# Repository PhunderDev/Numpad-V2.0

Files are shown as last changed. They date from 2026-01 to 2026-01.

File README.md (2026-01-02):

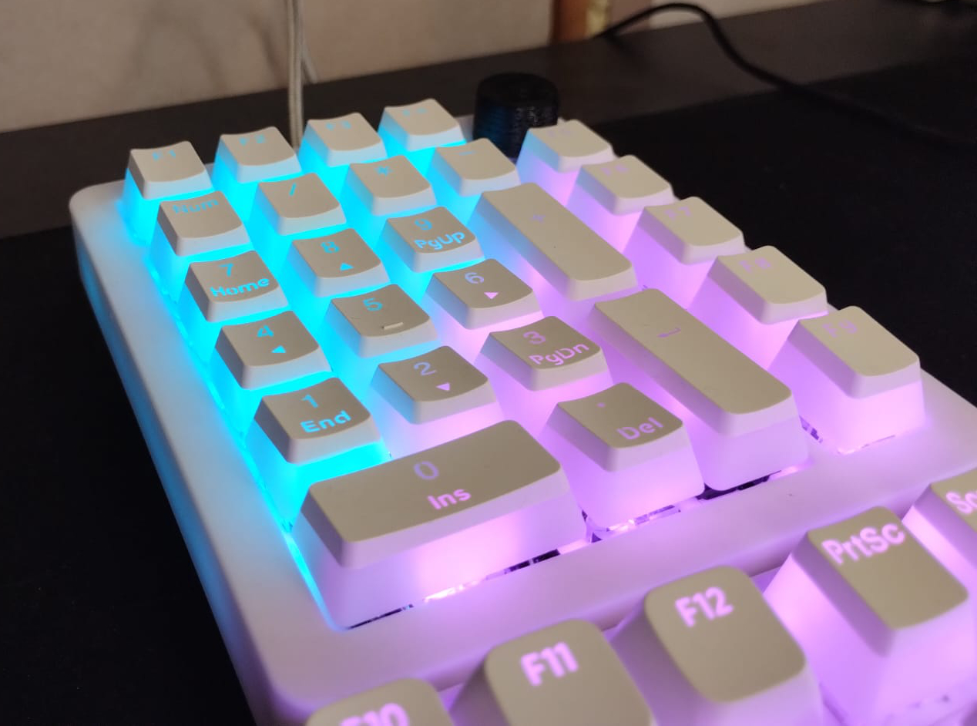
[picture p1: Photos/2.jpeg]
Numpad Photo


# About the project
This project is my answer to the lack of a satifying full-sized keyboard on the market (in a reasonable price). It is a numpad with 9 extra keys and a volume knob.
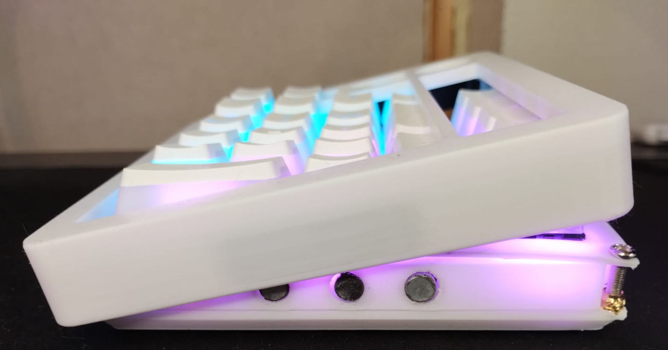
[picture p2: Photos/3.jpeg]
Numpad Magnets Photo
The numpad uses 6 magnets and magnetic tape embeded into the top case, which allow the user to switch the top case quickly, making customization easier. 

The firmware is written in C++ for raspberry pi pico (1), however it can surely be built for other microcontrollers.

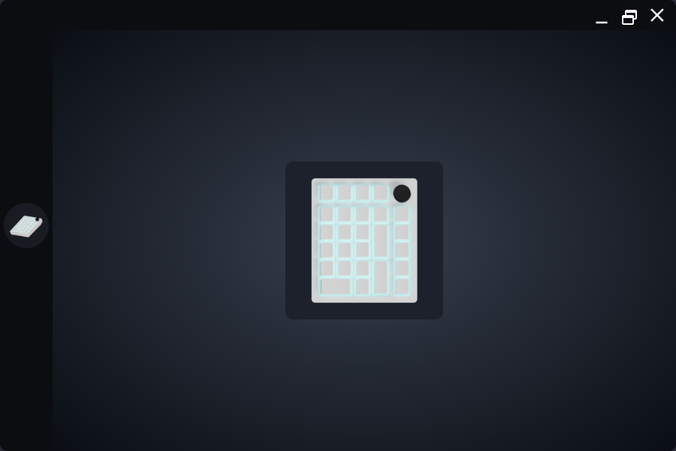
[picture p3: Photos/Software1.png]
Software Screenshot 1
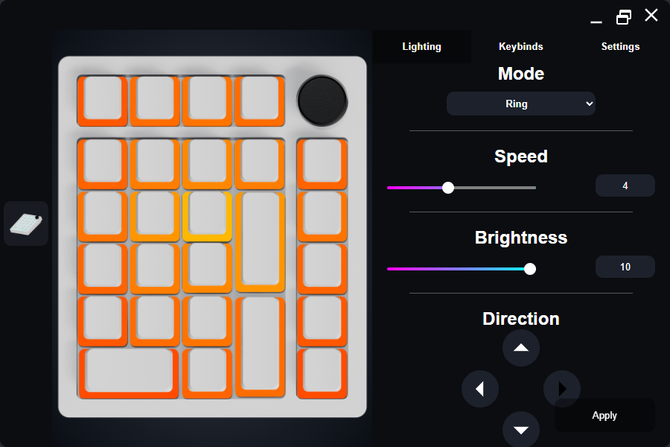
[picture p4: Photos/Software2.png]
Software Screenshot 2
The software part uses angular and electron (unfortunatelly your ram will likely suffer due to that, but the software doesn't need to be on all the time). The software allows the user to change the "global settings" of the lighting, and the "local settings" for each of the keys, not restricting to only the provided modes.   
No build setup is provided yet, but electron packager is included in the libraries already. You might have to tweak the build settings a bit.

Otherwise you can try the software by running the command
```bash
npm run electronTest
```

# Main Goal
The software is supposed to serve as a hub for custom RGB devices and includes a modular way of adding effects so adding any custom modes should be relatively easy.

# Project's Structure
The files are segregated depending on whether they are related to firmware, software, or physical build. The folder "Physical/Print Models" contains the STL files required to build the Numpad.

# Components
The following components were to assemble the numpad:
- Raspberry pi pico (1)
- Adafruit 4090 USB-C Breakout Board
- Addressable WS2812B LED strip
- EC12 20mm Rotary Encoder
- Magnetic Tape
- Magnets (6mm diameter | 3mm depth)
- 26 Switches (Any will work)
- Some jumper wires

# Assembly Instructions
Coming Soon

# Future of the project
The project is open for contributions and is supposed to be community-driven, therefore if there is any feature you would like to see-code it and share with the others.

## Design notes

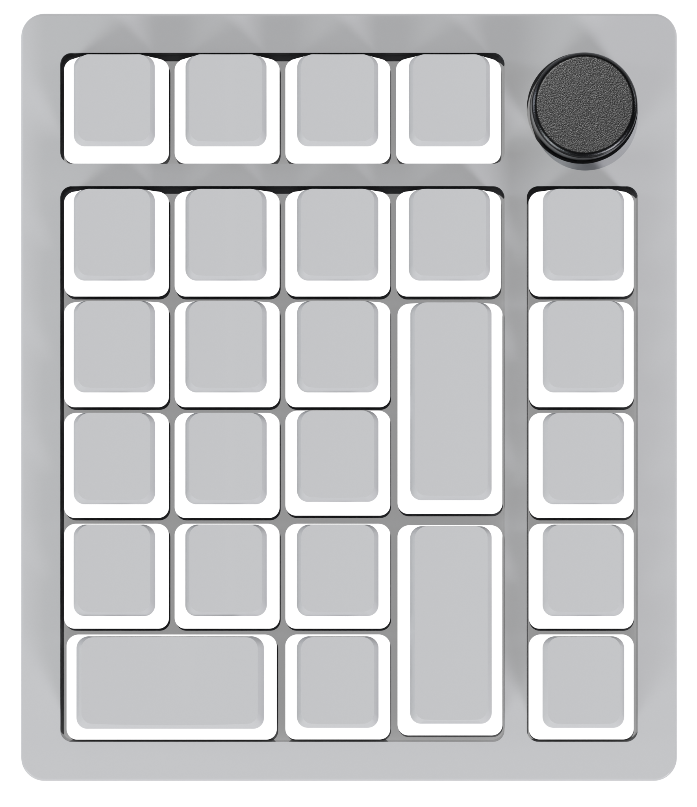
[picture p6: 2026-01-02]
Physical/Renders/Render1.png

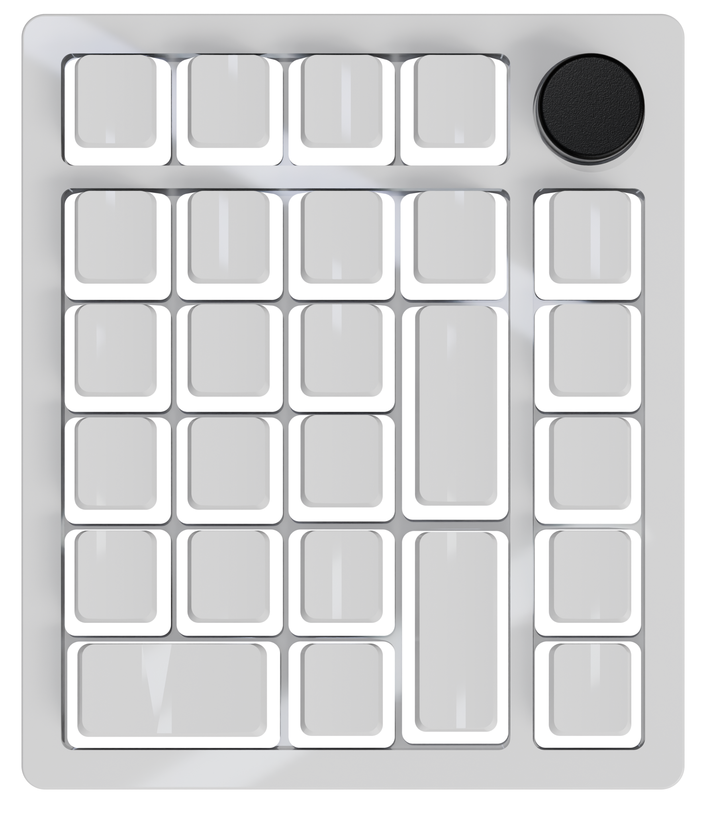
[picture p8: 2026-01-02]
Physical/Renders/Render4.png

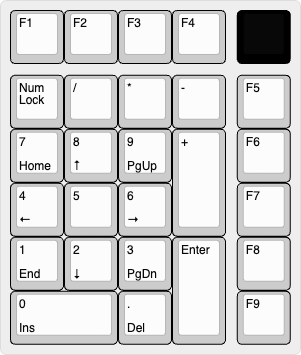
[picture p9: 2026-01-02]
Physical/Plate/keyboard-layout.png

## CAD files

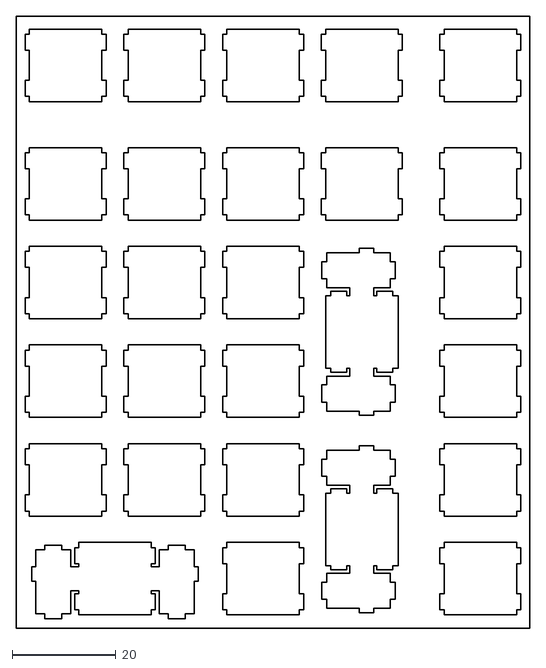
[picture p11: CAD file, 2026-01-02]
Physical/Plate/keyboard-layout.dxf
99.1 x 118.1

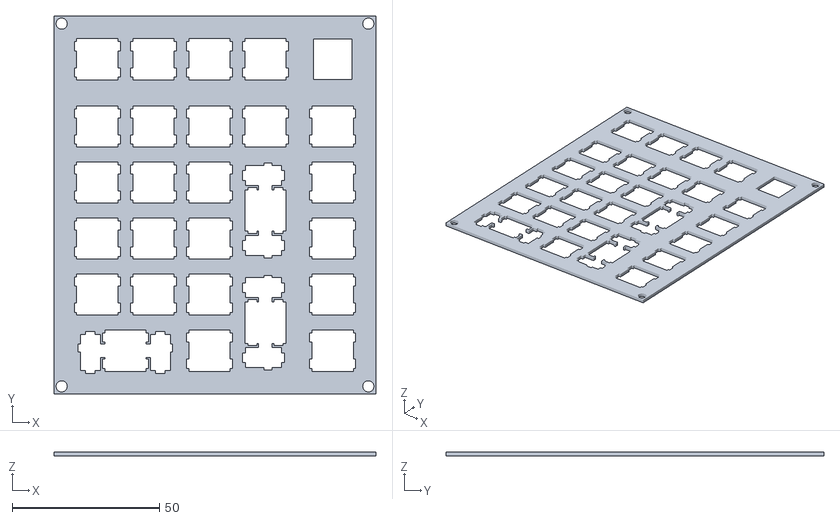
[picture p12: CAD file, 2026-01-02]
Physical/Print Models/Plate.stl
109.5 x 128.5 x 1.50

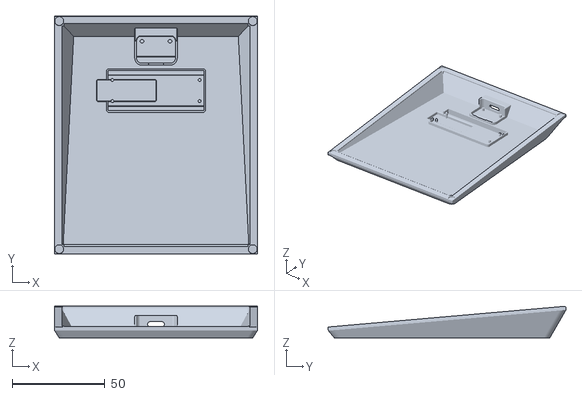
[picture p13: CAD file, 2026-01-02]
Physical/Print Models/Bottom Case.stl
109.5 x 128.2 x 17.0

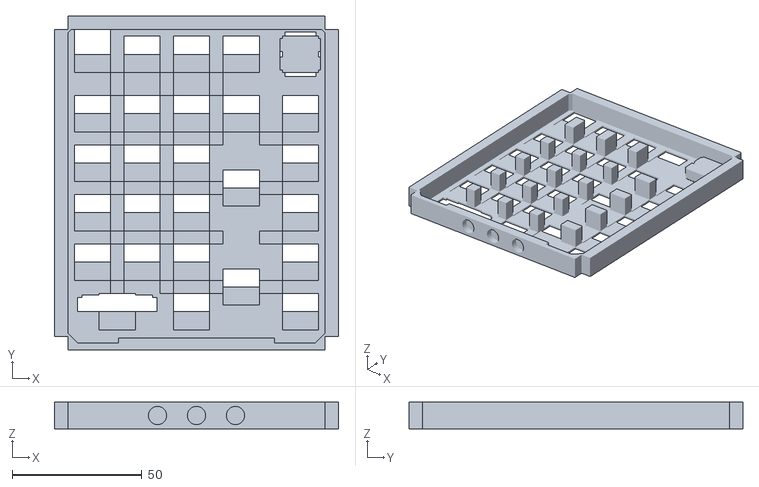
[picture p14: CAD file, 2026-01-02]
Physical/Print Models/Cables Separator.stl
109.5 x 128.5 x 10.2

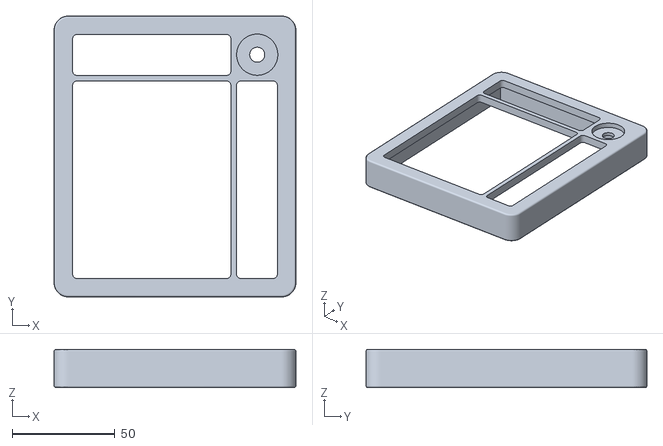
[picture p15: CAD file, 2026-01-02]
Physical/Print Models/Top Case.stl
117.7 x 136.7 x 18.7

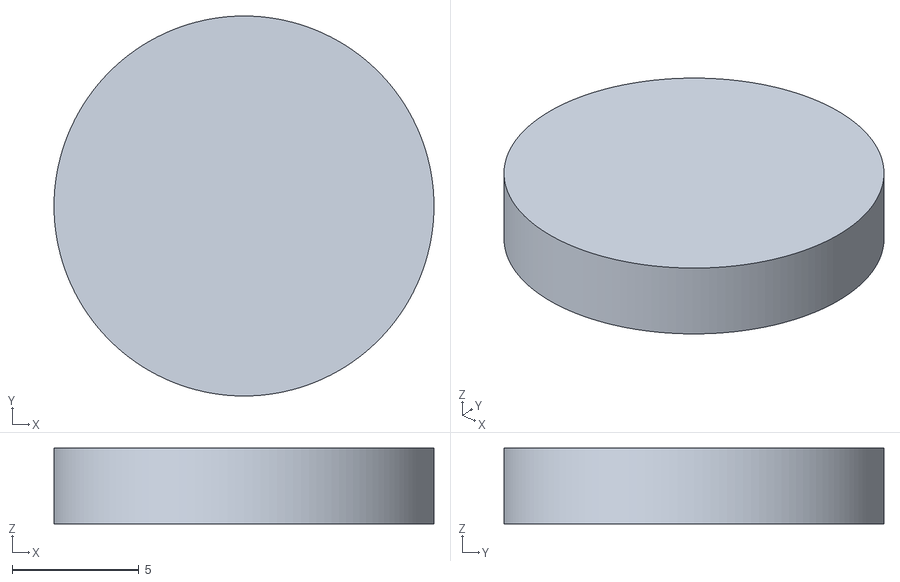
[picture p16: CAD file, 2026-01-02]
Physical/Print Models/Rubber Leg.stl
15.0 x 15.0 x 3.00

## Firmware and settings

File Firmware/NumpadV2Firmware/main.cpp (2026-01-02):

#include <stdlib.h>
#include <stdio.h>
#include <string.h>
#include <pico/stdio.h>
#include <pico/bootrom.h>
#include <hardware/gpio.h>

#include "bsp/board_api.h"
#include "tusb.h"
#include "usb_descriptors.h"

#include "WS2812.hpp"

#include "hardware/flash.h"
#include <tuple>
#include <algorithm>
#include <cmath>

// Start Address For Save Files In Flash
#define USER_DATA_FLASH_TARGET_OFFSET (PICO_FLASH_SIZE_BYTES - FLASH_SECTOR_SIZE)


#define LED_PIN 22
#define LED_LENGTH 26
#define ENCODER_SW 18
#define ENCODER_A 20
#define ENCODER_B 21
#define LEDMatrixWidth 5
#define LEDMatrixHeight 6
#define ConstantLEDSpeedMultiplier 20
#define ReverseKnob true
const int LEDDataLength = (LED_LENGTH * 7) + std::ceil((LED_LENGTH * 7) / (double)CFG_TUD_HID_EP_BUFSIZE);


//////////////////////////////////////////////////////
/// Wiring Config
//////////////////////////////////////////////////////
const int Columns[LEDMatrixWidth] = {6, 5, 4, 3, 2};
const int Rows[LEDMatrixHeight] = {7, 8, 9, 10, 11, 12};
const int DebounceTime = 10;
const int Knob_RotateDebounceTime = 10;
const int ConsumerDebounceTime = 300;
const int ConsumerEmptyDebounceTime = 50;
bool ConsumerEmptySent = false;
const int LEDRefreshTime = 20;
bool IsAsleep = false;

const int LEDMatrixIndexConfiguration[LEDMatrixHeight][LEDMatrixWidth] = {
  {0, 10, 11, 20, -1},
  {1, 9, 12, 19, 21},
  {2, 8, 13, 18, 22},
  {3, 7, 14, -1, 23},
  {4, 6, 15, 17, 24},
  {5, -1, 16, -1, 25}
}; 

bool CurrentReportMatrix[LEDMatrixHeight][LEDMatrixWidth] = {
  {false, false, false, false, false},
  {false, false, false, false, false},
  {false, false, false, false, false},
  {false, false, false, false, false},
  {false, false, false, false, false},
  {false, false, false, false, false}
};

int PreviousReportMatrix[LEDMatrixHeight][LEDMatrixWidth] = {
  {-1, -1, -1, -1, -1},
  {-1, -1, -1, -1, -1},
  {-1, -1, -1, -1, -1},
  {-1, -1, -1, -1, -1},
  {-1, -1, -1, -1, -1},
  {-1, -1, -1, -1, -1}
};

//////////////////////////////////////////////////////
/// Firmware Variables
//////////////////////////////////////////////////////
uint32_t DeltaTime = 0;
uint32_t LastTimeUpdated = 0;


//////////////////////////////////////////////////////
/// Keyboard Loop Variables
//////////////////////////////////////////////////////
uint32_t SwitchMatrix_DeltaTime = 0;
int CurrentColIndex = 0;
bool WaitingForDebounce = false;


uint32_t ReportSend_DeltaTime = 0;
uint32_t Knob_DeltaTime = 0;
uint32_t Knob_DebounceTime = Knob_RotateDebounceTime;
bool LastStateA = false;
bool ShouldDebounceKnob = false;




//////////////////////////////////////////////////////
/// LED Variables
//////////////////////////////////////////////////////
class LEDSettings {
  public:
  uint8_t StartColor_R;
  uint8_t StartColor_G;
  uint8_t StartColor_B;
  uint8_t Brightness;
  uint8_t Mode;
  uint8_t Speed;
  uint8_t Direction;

  uint8_t CurrentColor_R;
  uint8_t CurrentColor_G;
  uint8_t CurrentColor_B;
};
WS2812* ledStrip = nullptr;
int LastLEDSet = 0;
int LastLEDSettingsModified = 0;
uint32_t LED_DeltaTime = 0;
uint8_t LEDDataToSave[LEDDataLength];
int LastLEDDataToSaveIndex = 0;
LEDSettings LEDSettingsArray[LED_LENGTH];





//////////////////////////////////////////////////////
/// Device Settings
//////////////////////////////////////////////////////

uint8_t SwitchMatrixKeyBindConfiguration[LEDMatrixHeight][LEDMatrixWidth] = {
  {0x68, 0x69, 0x6A, 0x6B, 0x00},   // F13, F14, F15, F16, null
  {0x53, 0x54, 0x55, 0x56, 0x6C},   // NumLock, /, *, -, F17
  {0x5F, 0x60, 0x61, 0x57, 0x6D},   // 7, 8, 9, +, F18
  {0x5C, 0x5D, 0x5E, 0x00, 0x6E},   // 4, 5, 6, null, F19
  {0x59, 0x5A, 0x5B, 0x58, 0x6F},   // 1, 2, 3, ENTER, F20
  {0x62, 0x00, 0x63, 0x00, 0x70}    // 0, null, ., null, F21
};

uint32_t KeyboardPollingTime = 8;




//////////////////////////////////////////////////////
/// Flash Save & Load LEDs
//////////////////////////////////////////////////////

bool ProcessLEDSettings(uint8_t const* buffer, uint16_t bufsize) {
  
  LEDDataToSave[LastLEDDataToSaveIndex] = buffer[0];
  LastLEDDataToSaveIndex++;
  for(int i = 1; i < bufsize; i+=7) {

    int YInArray = LastLEDSet/LEDMatrixWidth;
    int XInArray = LastLEDSet%LEDMatrixWidth;
    while(LEDMatrixIndexConfiguration[YInArray][XInArray] == -1 && !(YInArray == LEDMatrixHeight -1 && XInArray == LEDMatrixWidth - 1)) {
      LastLEDSet++;
      YInArray = LastLEDSet/LEDMatrixWidth;
      XInArray = LastLEDSet%LEDMatrixWidth;
    }

    LEDSettings NewLEDSettings;
    NewLEDSettings.StartColor_R = buffer[i];
    NewLEDSettings.StartColor_G = buffer[i+1];
    NewLEDSettings.StartColor_B = buffer[i+2];
    NewLEDSettings.Mode = buffer[i+3];
    NewLEDSettings.Speed = buffer[i+4];
    NewLEDSettings.Brightness = (buffer[i+5]);
    NewLEDSettings.Direction = buffer[i+6];


    for(int e = 0; e < 7; e++) LEDDataToSave[LastLEDDataToSaveIndex+e] = buffer[i+e];
    LastLEDDataToSaveIndex+=7;


    NewLEDSettings.CurrentColor_R = NewLEDSettings.StartColor_R;
    NewLEDSettings.CurrentColor_G = NewLEDSettings.StartColor_G;
    NewLEDSettings.CurrentColor_B = NewLEDSettings.StartColor_B;

    LEDSettingsArray[LastLEDSettingsModified] = NewLEDSettings;

    float Brightness = NewLEDSettings.Brightness/10.0;

    (*ledStrip).setPixelColor(LEDMatrixIndexConfiguration[YInArray][XInArray], WS2812::RGB(NewLEDSettings.CurrentColor_R * Brightness, NewLEDSettings.CurrentColor_G * Brightness, NewLEDSettings.CurrentColor_B * Brightness));
    LastLEDSet++;
    LastLEDSettingsModified++;
    if(LEDMatrixIndexConfiguration[YInArray][XInArray] == LED_LENGTH - 1) {
      (*ledStrip).show();
      LastLEDSet = 0;
      LastLEDSettingsModified = 0;
      LastLEDDataToSaveIndex = 0;
      return true;
      break;
    }
  }
  return false;
}

void SaveLEDSettings(const uint8_t* data) {
    if (data == nullptr || LEDDataLength > FLASH_PAGE_SIZE) {
        return;
    }

    uint8_t buffer[FLASH_PAGE_SIZE];
    memset(buffer, 0xFF, sizeof(buffer)); // Erase the Buffer
    memcpy(buffer, data, LEDDataLength); // Set the Buffer

    flash_range_erase(USER_DATA_FLASH_TARGET_OFFSET, FLASH_SECTOR_SIZE);
    flash_range_program(USER_DATA_FLASH_TARGET_OFFSET, buffer, FLASH_PAGE_SIZE);
}

void LoadLEDSettings(void) {
    memcpy(LEDDataToSave, reinterpret_cast<const uint8_t*>(XIP_BASE + USER_DATA_FLASH_TARGET_OFFSET), LEDDataLength);
}



//////////////////////////////////////////////////////
/// USB HID
//////////////////////////////////////////////////////

void tud_hid_set_report_cb(uint8_t itf, uint8_t report_id, hid_report_type_t report_type, uint8_t const* buffer, uint16_t bufsize) {

    // buffer[0] => Type of update
    if (itf == ITF_NUM_HID2 && buffer[0] == 1 && bufsize == CFG_TUD_HID_EP_BUFSIZE){
      bool Finished = ProcessLEDSettings(buffer, bufsize);
      if(Finished) {
        SaveLEDSettings(LEDDataToSave);
      }

    }
}

uint16_t tud_hid_get_report_cb(uint8_t itf, uint8_t report_id, hid_report_type_t report_type, uint8_t* buffer, uint16_t reqlen) {
    return 0;
}


// PC Sleep
void tud_suspend_cb(bool remote_wakeup_en) {
  IsAsleep = true;
  (*ledStrip).fill(WS2812::RGB(0, 0, 0));
  (*ledStrip).show();
}
int InitLEDSettings();
// PC Wakey Wakey
void tud_resume_cb(void) {
  IsAsleep = false;
  InitLEDSettings();
}



//////////////////////////////////////////////////////
/// Keyboard Functionalities
//////////////////////////////////////////////////////
void send_keyboard_report(uint8_t modifier, uint8_t keycodes[6])
{
  if (!tud_ready()) return;

  // [modifier, reserved, keycode1, keycode2, ...]
  uint8_t report[8] = {0}; 
  report[0] = modifier;
  report[1] = 0x00;
  report[2] = keycodes[0];
  report[3] = keycodes[1];
  report[4] = keycodes[2];
  report[5] = keycodes[3];
  report[6] = keycodes[4];
  report[7] = keycodes[5];

  tud_hid_n_report(ITF_NUM_HID1, REPORT_ID_KEYBOARD, report, sizeof(report));
}

void send_consumer_report(uint16_t consumer_code)
{
  if (!tud_ready()) return;
  
  tud_hid_n_report(ITF_NUM_HID1, REPORT_ID_CONSUMER_CONTROL, &consumer_code, 2);
}

void SwitchMatrixLoop() {
  //Wait For The Right Time To Update

  if(!WaitingForDebounce) {
  
    gpio_put(Columns[CurrentColIndex], 1);
    WaitingForDebounce = true;
    return;
  }

  

  if(SwitchMatrix_DeltaTime >= DebounceTime) {
    // Register The Rows
    for(int row = 0; row < sizeof(Rows) / sizeof(Rows[0]); row++) {

      if(gpio_get(Rows[row]) != 0 && SwitchMatrixKeyBindConfiguration[row][CurrentColIndex] == 0x69) {
        if(ShouldDebounceKnob && Knob_DeltaTime < Knob_DebounceTime) continue;
        send_consumer_report(HID_USAGE_CONSUMER_SCAN_PREVIOUS);
        Knob_DebounceTime = ConsumerDebounceTime;
        ShouldDebounceKnob = true;
        ConsumerEmptySent = false;
        continue;
      }
      if(gpio_get(Rows[row]) != 0 && SwitchMatrixKeyBindConfiguration[row][CurrentColIndex] == 0x6A) {
        if(ShouldDebounceKnob && Knob_DeltaTime < Knob_DebounceTime) continue;
        send_consumer_report(HID_USAGE_CONSUMER_PLAY_PAUSE);
        Knob_DebounceTime = ConsumerDebounceTime;
        ShouldDebounceKnob = true;
        ConsumerEmptySent = false;
        continue;
      }
      if(gpio_get(Rows[row]) != 0 && SwitchMatrixKeyBindConfiguration[row][CurrentColIndex] == 0x6B) {
        if(ShouldDebounceKnob && Knob_DeltaTime < Knob_DebounceTime) continue;
        send_consumer_report(HID_USAGE_CONSUMER_SCAN_NEXT);
        Knob_DebounceTime = ConsumerDebounceTime;
        ShouldDebounceKnob = true;
        ConsumerEmptySent = false;
        continue;
      }

      CurrentReportMatrix[row][CurrentColIndex] = gpio_get(Rows[row]) != 0;
    }
    gpio_put(Columns[CurrentColIndex], 0);
    
    // Shift To The Next Column and/or Row if necessary
    CurrentColIndex += 1;
    if(CurrentColIndex == sizeof(Columns)/sizeof(Columns[0])) {CurrentColIndex = 0;}

    // Reset Timer
    SwitchMatrix_DeltaTime = 0;
    WaitingForDebounce = false;
  }



}

void KeyboardReportLoop() {
  if(ReportSend_DeltaTime < KeyboardPollingTime) return;
  
  uint8_t report[6] = {0, 0, 0, 0, 0, 0};

  int amount = 0;
  for(int col = 0; col < sizeof(Columns) / sizeof(Columns[0]); col++) {
    for(int row = 0; row < sizeof(Rows) / sizeof(Rows[0]); row++) {

      if(amount >= 6) break;

      if(!CurrentReportMatrix[row][col] && PreviousReportMatrix[row][col] != -1) {
        report[PreviousReportMatrix[row][col]] = 0x00;
        // Set as Sent/Released
        PreviousReportMatrix[row][col] = -1;
        amount += 1;
      }
      else if(CurrentReportMatrix[row][col] && PreviousReportMatrix[row][col] == -1) {
        report[amount] = SwitchMatrixKeyBindConfiguration[row][col];
        // Set as Pressed
        PreviousReportMatrix[row][col] = amount;
        amount += 1;
      }
    }

    if(amount == 6) break;
  }

  if(amount != 0) {
    if(IsAsleep) {
      tud_remote_wakeup();
      return;
    }
    send_keyboard_report(0, report);
  }
}


void KnobReportLoop() {
  if(ShouldDebounceKnob && Knob_DeltaTime < Knob_DebounceTime) {
    if(Knob_DeltaTime >= ConsumerEmptyDebounceTime && !ConsumerEmptySent) {
      ConsumerEmptySent = true;
      send_consumer_report(0);
    }
    return;
  }
  ShouldDebounceKnob = false;
  Knob_DeltaTime = 0;

  if(gpio_get(ENCODER_SW) == 0) {
    send_consumer_report(HID_USAGE_CONSUMER_MUTE);
    Knob_DebounceTime = ConsumerDebounceTime;
    ShouldDebounceKnob = true;
    ConsumerEmptySent = false;
    return;
  }

  Knob_DebounceTime = Knob_RotateDebounceTime;

  int StateA = gpio_get(ENCODER_A);
  int StateB = gpio_get(ENCODER_B);

  if (StateA != LastStateA) {
    if ((ReverseKnob && StateA == StateB) || (!ReverseKnob && StateA != StateB)) send_consumer_report(HID_USAGE_CONSUMER_VOLUME_INCREMENT);
    else send_consumer_report(HID_USAGE_CONSUMER_VOLUME_DECREMENT);

    Knob_DebounceTime = Knob_RotateDebounceTime;
    ShouldDebounceKnob = true;
    ConsumerEmptySent = false;
  }
  LastStateA = StateA;


}




std::tuple<int, int, int> CycleRGB(int r, int g, int b, float step) {
    float NewR = (float)(r);
    float NewG = (float)(g);
    float NewB = (float)(b);

    // Detect Part
    float MaxVal = std::max({NewR, NewG, NewB});
    float MinVal = std::min({NewR, NewG, NewB});
    float DeltaVal = MaxVal - MinVal;

    // 1530 = All Values in a Hue Cycle
    // Calculate the Starting Position
    float Position = 0.0f;
    if (DeltaVal > 0.0f) {
        if (MaxVal == NewR) {
            Position = (NewG - NewB) / DeltaVal * 60.0f;
            if (Position < 0.0f) Position += 360.0f;
        } else if (MaxVal == NewG) {
            Position = ((NewB - NewR) / DeltaVal + 2.0f) * 60.0f;
        } else {
            Position = ((NewR - NewG) / DeltaVal + 4.0f) * 60.0f;
        }
        // 1530 => 360deg
        Position = Position / 360.0f * 1530.0f;
    }

    // Progress Through the Cycle Radially
    float RadialStep = step * (1530.0f / 360.0f);
    Position = std::fmod(Position + RadialStep, 1530.0f);
    if (Position < 0.0f) Position += 1530.0f;

    // Find Current Stage
    int Stage = (int)(Position / 255.0f);
    float FractionValue = std::fmod(Position, 255.0f);

    switch (Stage) {
        case 0:
            NewR = 255.0f;
            NewG = FractionValue;
            NewB = 0.0f;
            break;
        case 1:
            NewR = 255.0f - FractionValue;
            NewG = 255.0f;
            NewB = 0.0f;
            break;
        case 2:
            NewR = 0.0f;
            NewG = 255.0f;
            NewB = FractionValue;
            break;
        case 3:
            NewR = 0.0f;
            NewG = 255.0f - FractionValue;
            NewB = 255.0f;
            break;
        case 4:
            NewR = FractionValue;
            NewG = 0.0f;
            NewB = 255.0f;
            break;
        case 5:
            NewR = 255.0f;
            NewG = 0.0f;
            NewB = 255.0f - FractionValue;
            break;
    }

    int ResultR = std::clamp((int)(std::round(NewR)), 0, 255);
    int ResultG = std::clamp((int)(std::round(NewG)), 0, 255);
    int ResultB = std::clamp((int)(std::round(NewB)), 0, 255);

    return {ResultR, ResultG, ResultB};
}

void LEDLoop() {

  if(LED_DeltaTime < LEDRefreshTime) return;
  
  int CurrentLEDInMatrix = 0;
  for(int LEDIndex = 0; LEDIndex < LED_LENGTH; LEDIndex++) {
    int YInArray = CurrentLEDInMatrix/LEDMatrixWidth;
    int XInArray = CurrentLEDInMatrix%LEDMatrixWidth;
    while(LEDMatrixIndexConfiguration[YInArray][XInArray] == -1 && !(YInArray == LEDMatrixHeight - 1 && XInArray == LEDMatrixWidth - 1)) {
      CurrentLEDInMatrix++;
      YInArray = CurrentLEDInMatrix/LEDMatrixWidth;
      XInArray = CurrentLEDInMatrix%LEDMatrixWidth;
    }

    if(LEDSettingsArray[LEDIndex].Mode == 1) {
      auto [NewR, NewG, NewB] = CycleRGB(LEDSettingsArray[LEDIndex].CurrentColor_R, LEDSettingsArray[LEDIndex].CurrentColor_G, LEDSettingsArray[LEDIndex].CurrentColor_B, ((float)(LEDSettingsArray[LEDIndex].Speed) * ((float)LED_DeltaTime/1000.0) * ConstantLEDSpeedMultiplier));
      LEDSettingsArray[LEDIndex].CurrentColor_R = NewR;
      LEDSettingsArray[LEDIndex].CurrentColor_G = NewG;
      LEDSettingsArray[LEDIndex].CurrentColor_B = NewB;
    }

    float Brightness = LEDSettingsArray[LEDIndex].Brightness / 10.0f;
    (*ledStrip).setPixelColor(LEDMatrixIndexConfiguration[YInArray][XInArray], WS2812::RGB(LEDSettingsArray[LEDIndex].CurrentColor_R * Brightness, LEDSettingsArray[LEDIndex].CurrentColor_G * Brightness, LEDSettingsArray[LEDIndex].CurrentColor_B * Brightness));

    

    CurrentLEDInMatrix++;
  }
  (*ledStrip).show();
  LED_DeltaTime = 0;
}

//////////////////////////////////////////////////////
/// Firmware Updates
//////////////////////////////////////////////////////
void EnterBootselMode() {
  (*ledStrip).fill(WS2812::RGB(255, 255, 255));
  (*ledStrip).show();
  reset_usb_boot(0, 0);
}

void UpdateTimers() {
  // Update Global DeltaTimes
  uint32_t TimeNow = to_ms_since_boot(get_absolute_time());
  DeltaTime = TimeNow - LastTimeUpdated;
  LastTimeUpdated = TimeNow;

  // Update Local DeltaTimes
  SwitchMatrix_DeltaTime += DeltaTime;
  ReportSend_DeltaTime += DeltaTime;
  LED_DeltaTime += DeltaTime;
  if(ShouldDebounceKnob) Knob_DeltaTime += DeltaTime;
}

int InitLEDSettings() {
  LoadLEDSettings();
  uint8_t DataToProcess[CFG_TUD_HID_EP_BUFSIZE];
  for(int i = 0; i < LEDDataLength; i++) {
    DataToProcess[i % CFG_TUD_HID_EP_BUFSIZE] = LEDDataToSave[i];
    if((i+1) % CFG_TUD_HID_EP_BUFSIZE == 0 || i == 184) {
      ProcessLEDSettings(DataToProcess, CFG_TUD_HID_EP_BUFSIZE);
    }
  }
 return 0;
}


int Init() {

  
    try {
      ledStrip = new WS2812(
        LED_PIN,
        LED_LENGTH,
        pio0,
        0,
        WS2812::FORMAT_GRB
      );
    } catch(...) {
        return 1;
    }



    (*ledStrip).fill(WS2812::RGB(255, 0, 255));
    (*ledStrip).show();

    //Init Rows & Columns
    for(int i = 0; i < sizeof(Columns) / sizeof(Columns[0]); i++) {
      gpio_init(Columns[i]);
      gpio_set_dir(Columns[i], GPIO_OUT);
    }

    for(int i = 0; i < sizeof(Rows) / sizeof(Rows[0]); i++) {
      gpio_init(Rows[i]);
      gpio_set_dir(Rows[i], GPIO_IN);
    }

    // Init Knob
    gpio_init(ENCODER_SW);
    gpio_set_dir(ENCODER_SW, GPIO_IN);
    gpio_pull_up(ENCODER_SW);

    gpio_init(ENCODER_A);
    gpio_init(ENCODER_B);
    gpio_set_dir(ENCODER_A, GPIO_IN);
    gpio_set_dir(ENCODER_B, GPIO_IN);
    gpio_pull_up(ENCODER_A);
    gpio_pull_up(ENCODER_B);


    return 0;
}


int main(void)
{
  board_init();
  int initResult = Init();

  // Enter Bootsel If 1/0 Is Pressed
  gpio_put(Columns[1], 1);
  sleep_ms(DebounceTime);
  if(gpio_get(Rows[0]) != 0) {
      EnterBootselMode();
      return 0; 
  }
  gpio_put(Columns[1], 0);

  if(initResult != 0) {
    return 0;
  }


  tusb_rhport_init_t dev_init = {
    .role = TUSB_ROLE_DEVICE,
    .speed = TUSB_SPEED_AUTO
  };
  tusb_init(BOARD_TUD_RHPORT, &dev_init);
  board_init_after_tusb();

  InitLEDSettings();

  // Disable OnBoard LED
  board_led_write(false);

  while (true)
  {
    tud_task();
    if (!tud_suspended() && tud_mounted() && IsAsleep) {
      IsAsleep = false;
      InitLEDSettings();
      continue;
    }

    UpdateTimers();
    SwitchMatrixLoop();
    KeyboardReportLoop();
    if(!IsAsleep) LEDLoop();
    KnobReportLoop();
  }
}

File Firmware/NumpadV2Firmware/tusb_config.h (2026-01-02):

/*
 * The MIT License (MIT)
 *
 * Copyright (c) 2019 Ha Thach (tinyusb.org)
 *
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
 */

#ifndef _TUSB_CONFIG_H_
#define _TUSB_CONFIG_H_

#ifdef __cplusplus
 extern "C" {
#endif

//--------------------------------------------------------------------+
// Board Specific Configuration
//--------------------------------------------------------------------+

// RHPort number used for device can be defined by board.mk, default to port 0
#ifndef BOARD_TUD_RHPORT
#define BOARD_TUD_RHPORT      0
#endif

// RHPort max operational speed can defined by board.mk
#ifndef BOARD_TUD_MAX_SPEED
#define BOARD_TUD_MAX_SPEED   OPT_MODE_DEFAULT_SPEED
#endif

//--------------------------------------------------------------------
// COMMON CONFIGURATION
//--------------------------------------------------------------------

// defined by compiler flags for flexibility
#ifndef CFG_TUSB_MCU
#error CFG_TUSB_MCU must be defined
#endif

#ifndef CFG_TUSB_OS
#define CFG_TUSB_OS           OPT_OS_NONE
#endif

#ifndef CFG_TUSB_DEBUG
#define CFG_TUSB_DEBUG        0
#endif

// Enable Device stack
#define CFG_TUD_ENABLED       1

// Default is max speed that hardware controller could support with on-chip PHY
#define CFG_TUD_MAX_SPEED     BOARD_TUD_MAX_SPEED

/* USB DMA on some MCUs can only access a specific SRAM region with restriction on alignment.
 * Tinyusb use follows macros to declare transferring memory so that they can be put
 * into those specific section.
 * e.g
 * - CFG_TUSB_MEM SECTION : __attribute__ (( section(".usb_ram") ))
 * - CFG_TUSB_MEM_ALIGN   : __attribute__ ((aligned(4)))
 */
#ifndef CFG_TUSB_MEM_SECTION
#define CFG_TUSB_MEM_SECTION
#endif

#ifndef CFG_TUSB_MEM_ALIGN
#define CFG_TUSB_MEM_ALIGN        __attribute__ ((aligned(4)))
#endif

//--------------------------------------------------------------------
// DEVICE CONFIGURATION
//--------------------------------------------------------------------

#ifndef CFG_TUD_ENDPOINT0_SIZE
#define CFG_TUD_ENDPOINT0_SIZE    64
#endif

//------------- CLASS -------------//
#define CFG_TUD_CDC               0
#define CFG_TUD_MSC               0
#define CFG_TUD_HID               2
#define CFG_TUD_MIDI              0
#define CFG_TUD_VENDOR            0

// HID buffer size Should be sufficient to hold ID (if any) + Data
#define CFG_TUD_HID_EP_BUFSIZE    64

#ifdef __cplusplus
 }
#endif

#endif /* _TUSB_CONFIG_H_ */
